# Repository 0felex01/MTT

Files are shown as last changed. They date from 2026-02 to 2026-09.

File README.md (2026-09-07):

# MTT (Movie-to-Text)
Offline SRT Reader for Arduino Uno R4 WiFi

Eventually capture footage of device in action and place here.

# Equipment
- [SD Card Reader](https://www.amazon.com/HiLetgo-Adater-Interface-Conversion-Arduino/dp/B07BJ2P6X6)
- [OLED Display](https://www.amazon.com/DWEII-Display-SSD1309-Interface-Electronic/dp/B0B2R3RBKL)
- [PowerBoost 1000C Battery Charger Circuit](https://www.adafruit.com/product/2465)
- [3.7V 1000mAh Battery](https://www.amazon.com/1000mAh-Lithium-Polymer-Rechargeable-Connector/dp/B0C2KNZBPD)

# Features
- File selection
- Timestamp selection
- Pausing and resuming
- Advancing and rewinding
- Full English and Japanese subtitles support

# Nice future ideas
- Change how to process the newlines in each segment to better align with the smaller display
- Get a bigger display, further research indicates this may not be practical.
- Add .sub support

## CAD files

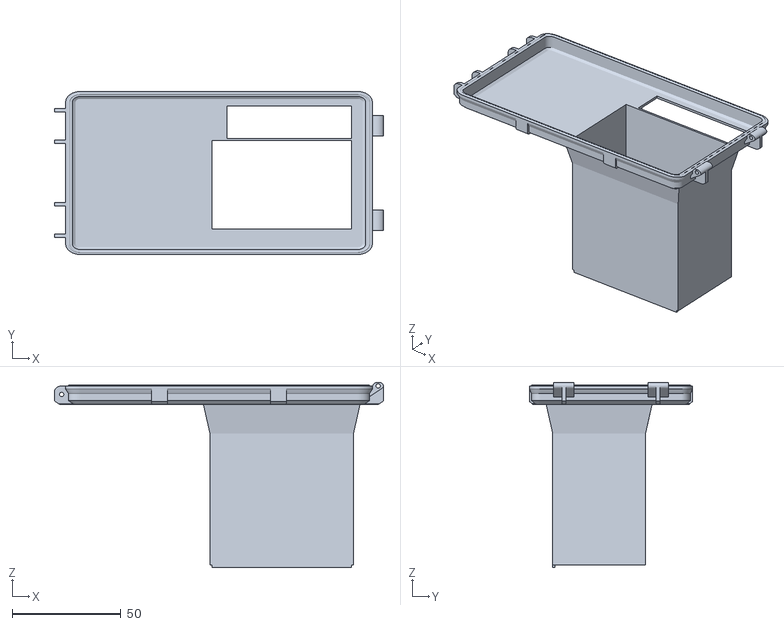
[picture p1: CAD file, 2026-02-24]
Blender/MTT top.stl
151.0 x 74.8 x 85.1

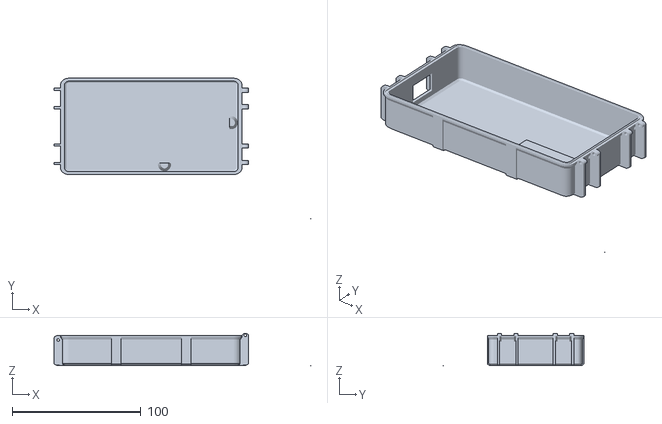
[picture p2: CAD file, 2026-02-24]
Blender/MTT bottom.stl
200.0 x 109.5 x 25.0

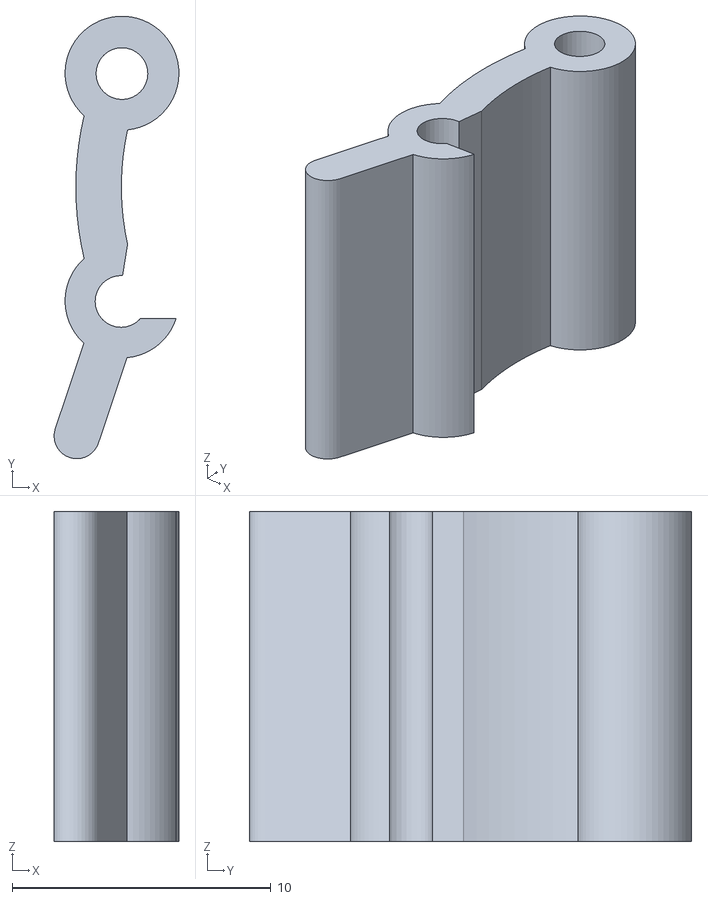
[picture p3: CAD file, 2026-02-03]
Blender/MTT Latches.stl
4.82 x 17.1 x 12.8

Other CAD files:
Blender/MTT Latches.blend
Blender/MTT bottom.blend
Blender/MTT top.blend

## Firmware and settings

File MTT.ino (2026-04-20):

#include <Arduino.h>

#define SD_CS 7
#define OLED_RST 8

#define SD_WAITING_MESSAGE "Waiting for SD"
#define TIME_GREETING_MESSAGE "Select your desired time"
#define RESET_MESSAGE "You may reset now"
#define CURSOR_SHAPE ">"
#define SRT_FILE_EXTENSION ".srt"
#define INITAL_TIMESTAMP "00:00:00:00"
#define MAX_ROWS 8

uint8_t DISPLAY_HEIGHT = 64;
uint8_t DISPLAY_WIDTH = 128;
uint8_t TILE_HEIGHT = 8;
uint8_t TILE_WIDTH = 8;
uint8_t FONT_HEIGHT = 5;
uint8_t DISPLAY_BOTTOM_ROW_TILE_X = 0;
uint8_t DISPLAY_BOTTOM_ROW_TILE_Y = (DISPLAY_HEIGHT / TILE_HEIGHT - 1);
uint8_t DISPLAY_BOTTOM_ROW_PIXEL_Y = (DISPLAY_BOTTOM_ROW_TILE_Y + 1) * TILE_HEIGHT;
uint8_t DISPLAY_TILE_WIDTH = DISPLAY_WIDTH / TILE_WIDTH;
uint8_t DISPLAY_BOTTOM_ROW_AREA_HEIGHT = TILE_HEIGHT / TILE_HEIGHT;

#include <U8g2lib.h>
#include <SPI.h>
#include <SdFat.h>
#include "OLED.h"
#include "PBs.h"
#include "SD_Reader.h"
#include "SRT.h"
#include "UI.h"

void setup() {
  Serial.begin(921600);
  while (!Serial);

	// UI
	String cursor = String(CURSOR_SHAPE);

  // Locale
  String locale = "EN";

  // Init PBs
  pinMode(PB_LEFT, INPUT_PULLUP);
  pinMode(PB_DOWN, INPUT_PULLUP);
  pinMode(PB_UP, INPUT_PULLUP);
  pinMode(PB_RIGHT, INPUT_PULLUP);
  pinMode(PB_B, INPUT_PULLUP);
  pinMode(PB_A, INPUT_PULLUP);

  // // Init OLED
  OLED_begin();

  // Init SD
  SdFat sd;
  OLED_print(SD_WAITING_MESSAGE, locale);
  /* while (!sd.begin(SD_CS, SPI_EIGHTH_SPEED)); */
  while (!sd.begin(SD_CS, SPI_HALF_SPEED));
  /* while (!sd.begin(SD_CS, SPI_DIV3_SPEED)); */

  // Read Files
  String files[MAX_FILES];
  unsigned int files_count = get_files(files);
  unsigned int cursor_pos = 0;
  files[0] = cursor + files[0]; // Cursor on first file
  draw_files(files, files_count, cursor_pos, "EN");
  draw_locale(locale, "EN");

  // File Select
  int input = 0;
  bool redraw = false;

  // Timestamps
  long periodic_times[PERIODIC_SIZE]; // Used to go to the closest subtitle after user provides time
  for (unsigned int i = 0; i < PERIODIC_SIZE; ++i) {
    periodic_times[i] = -1;
  }
  long periodic_pos[PERIODIC_SIZE]; // Used to go back and forth in subtitles
  for (unsigned int i = 0; i < PERIODIC_SIZE; ++i) {
    periodic_pos[i] = -1;
  }

  // Main Loop
  while (true) {
    input = check_buttons();
    switch (input) {
		case PB_DOWN: // Down one file
			if (cursor_pos < (files_count - 1)) {
				files[cursor_pos] = files[cursor_pos].substring(1);
				++cursor_pos;
				files[cursor_pos] = cursor + files[cursor_pos];
				redraw = true;
			}
			break;

		case PB_UP: // Up one file
			if (cursor_pos > 0) {
				files[cursor_pos] = files[cursor_pos].substring(1);
				--cursor_pos;
				files[cursor_pos] = cursor + files[cursor_pos];
				redraw = true;
			}
			break;

    case PB_B: // Switch locale
      if (locale == "EN") {
        locale = "JP";
      } else {
        locale = "EN";
      }
      redraw = true;
      break;

		case PB_A: // Select file
			String filename = files[cursor_pos].substring(1) + SRT_FILE_EXTENSION;

			SdFile subs;
			subs.open(filename.c_str(), O_READ);
			long amount_of_subs = gather_timestamps(subs, periodic_times, periodic_pos);

			// Prompt user to select time
			String current_timestamp = INITAL_TIMESTAMP;
			long chosen_time = 0;
			cursor_pos = 0;
			chosen_time = prompt_for_time(input, current_timestamp);

			// Skip to time
			bool skip_check = false;  // If the time is 0 or longer than the last subtitle, don't bother checking
			if (chosen_time == 0) {
				skip_check = true;
			}
			if (chosen_time > periodic_times[amount_of_subs - 1]) {
				subs.seekSet(periodic_pos[amount_of_subs - 1]);
				skip_check = true;
			}

			if (!skip_check) {
				for (long i = 0; i < amount_of_subs; ++i) {
					if (chosen_time < periodic_times[i]) {
						subs.seekSet(periodic_pos[i - 1]);
						break;
					}
				}
			}

			// Display subs
			subtitle first_subtitle;
			subtitle second_subtitle;

      // Populate first two subtitles then start rendering
      if (first_subtitle.index == 0) {
        read_subtitle(first_subtitle, subs);
      }
      if (second_subtitle.index == 0) {
        read_subtitle(second_subtitle, subs);
      }
      display_subs(subs, locale, periodic_times, periodic_pos, amount_of_subs, first_subtitle, second_subtitle);

			subs.close();
      Serial.println("End of subtitles");
			break;
    }

    if (redraw) {
      draw_files(files, files_count, cursor_pos, "EN");
      draw_locale(locale, "EN");
      redraw = false;
    }
  }
}

void loop() {
}

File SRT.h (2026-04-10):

#include <stdint.h>

#define LINE_FEED 10
#define CARRIAGE_RETURN 13
#define PERIODIC_SIZE 2000

#define LAST_SUBTITLE_RETURN -1
#define CLOSED_FILE_RETURN -2

#define GAP_MODE 1
#define SUBTITLES_MODE 2

#define SPEED_ADJUSTMENT_INCREMENTS 0.01
#define STARTING_FRAMES 100

struct subtitle {
  long index = 0;
  long from_time = 0;  // ms
  long to_time = 0;    // ms
  long duration = 0;   // ms
  String dialogue = "";
};

String read_next_line(SdFile& subs) {
  int data = 0;
  String buf;

  do {
    data = subs.read();
    buf += char(data);
  } while (data >= 0 && (data != LINE_FEED && data != CARRIAGE_RETURN));
  subs.read();  // Advance to next line

  return buf;
}

void go_to_prev_line(SdFile& subs) {
  int data = 0;
  unsigned int linefeed_count = 0;

  while (true) {
    if (subs.curPosition() <= 2) {
      return;
    }

    data = subs.read();
    if (data == LINE_FEED) {
      ++linefeed_count;
      if (linefeed_count == 6) {
        return;
      }
    }

    subs.seekSet(subs.curPosition() - 2);
  }
}

long calculate_from_time(const String& timestamps) {

  const char* ts = timestamps.c_str();

  int h = (ts[0] - '0') * 10 + (ts[1] - '0');
  int m = (ts[3] - '0') * 10 + (ts[4] - '0');
  int s = (ts[6] - '0') * 10 + (ts[7] - '0');
  int ms = (ts[9] - '0') * 100 + (ts[10] - '0') * 10 + (ts[11] - '0');

  return (long)h * 3600000L + (long)m * 60000L + (long)s * 1000L + ms;
}

long calculate_to_time(const String& timestamps) {

  const char* ts = timestamps.c_str() + 17;

  int h = (ts[0] - '0') * 10 + (ts[1] - '0');
  int m = (ts[3] - '0') * 10 + (ts[4] - '0');
  int s = (ts[6] - '0') * 10 + (ts[7] - '0');
  int ms = (ts[9] - '0') * 100 + (ts[10] - '0') * 10 + (ts[11] - '0');

  return (long)h * 3600000L + (long)m * 60000L + (long)s * 1000L + ms;
}

String clean_formatting(String message) {
  const char* tags[] = {
    "<b>", "</b>",
    "<i>", "</i>",
    "<u>", "</u>"
  };

  for (const char* tag : tags) {
    message.replace(tag, "");
  }

  message.replace("\r", "");
  return message;
}

String word_wrap(String message) {
  String result = "";

  unsigned int line_start = 0;
  unsigned int message_len = message.length();
  while (line_start < message_len) {
    // Find the end of the current line or existing newline
    int line_end = message.indexOf('\n', line_start);
    if (line_end == -1) line_end = message_len;

    String line = message.substring(line_start, line_end);
    unsigned int line_len = line.length();

    // Wrap the line if it's too long
    int start = 0;
    while ((unsigned int)start < line_len) {
      int end = start + MAX_CHAR_PER_LINE;
      if ((unsigned int)end >= line_len) {
        end = line_len;
      } else {
        // Find last space or punctuation before max width
        int wrap_pos = -1;
        for (int i = end; i > start; i--) {
          char c = line[i];
          if (c == ' ' || c == '?' || c == '.' || c == ',' || c == '!') {
            wrap_pos = i + 1;  // include punctuation/space
            break;
          }
        }
        if (wrap_pos != -1) end = wrap_pos;
      }

      result += line.substring(start, end);
      result += '\n';

      start = end;
      // Skip leading spaces
      while ((unsigned int)start < line_len && line[start] == ' ') start++;
    }

    line_start = line_end + 1;  // skip past existing newline
  }

  // Replace " -" with "\n-" as before
  result.replace(" -", "\n-");

  return result;
}

void read_subtitle(subtitle& given_subtitle, SdFile& subs) {
  // Subtitle index, skip
  long index = read_next_line(subs).toInt();
  given_subtitle.index = index;

  // Timestamps
  String timestamps = read_next_line(subs);
  long from_time = calculate_from_time(timestamps);
  long to_time = calculate_to_time(timestamps);
  /* long subtitles_duration = to_time - from_time; */
  given_subtitle.from_time = from_time;
  given_subtitle.to_time = to_time;
  long duration = to_time - from_time;
  given_subtitle.duration = duration;

  // Get all of the dialogue
  String dialogue = "";
  String current_read = "something";
  while (current_read.length() > 1) {
    current_read = read_next_line(subs);
    dialogue += current_read + "\n";
  }
  given_subtitle.dialogue = dialogue;

  return;
}

void transfer_subtitles(subtitle& first_subtitle, subtitle& second_subtitle) {
  subtitle temp = first_subtitle;
  first_subtitle = second_subtitle;
  second_subtitle = temp;
  second_subtitle.index = 0;
}

long gather_timestamps(SdFile& subs, long periodic_times[PERIODIC_SIZE], long periodic_pos[PERIODIC_SIZE]) {
  long periodic_idx = 0;
  long current_line = 0;
  long subs_counter = 0;

  while (subs.available()) {
    ++subs_counter;

    periodic_pos[periodic_idx] = subs.curPosition();
    read_next_line(subs);
    ++current_line;

    String timestamps = read_next_line(subs);
    ++current_line;

    long from_time = calculate_from_time(timestamps);
    periodic_times[periodic_idx] = from_time;
    ++periodic_idx;

    String current_message_line;
    do {
      current_message_line = read_next_line(subs);
      ++current_line;
    } while (current_message_line.length() > 1);
  }

  subs.seekSet(0);
  return subs_counter;
}

String make_paused_line(long timestamp) {
  long hours = timestamp / 3600000;
  timestamp %= 3600000;

  long minutes = timestamp / 60000;
  timestamp %= 60000;

  long seconds = timestamp / 1000;
  long millis = timestamp % 1000;

  char buffer[19];
  sprintf(buffer, "|| %02lu:%02lu:%02lu,%03lu", hours, minutes, seconds, millis);

  return String(buffer);
}
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

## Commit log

2024-11-03 *FIRST REAL TEST BUILD* added skipping to time and started putting some UI functions to UI.
    [MTT.ino, SRT.h]
2024-11-10 First real success test (still janky but didn't quit using device mid movie) Ignore hidden files Refactored main subtitles logic loop Added support for different modes with said logic loop (GAP and S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
    [MTT.ino, SRT.h]
2024-11-23 Resolved the compiler warnings and added some extra things.
    [SRT.h]
2025-03-15 sent out first pcb order
    [Peripherals Board-B_Cu.gbr, Peripherals Board-B_Mask.gbr, Peripherals Board-B_Paste.gbr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]
2025-05-03 added PBs to PCB and changed PB definitions to be reversed to accomodate PCB better
    [Peripherals Board-B_Cu.gbr, Peripherals Board-B_Mask.gbr, Peripherals Board-B_Paste.gbr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]
2025-05-03 made gerber zip
    [Peripherals Board-B_Cu.gbr, Peripherals Board-B_Mask.gbr, Peripherals Board-B_Paste.gbr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]
2025-05-18 pushbuttons were too far apart, made them 5.08mm instead of ~6mm
    [Peripherals Board-B_Cu.gbr, Peripherals Board-B_Mask.gbr, Peripherals Board-B_Paste.gbr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]
2025-09-07 fixes from test run today
    [MTT.ino]
2025-09-21 fixed rewind, added more timing logic, test run
    [SRT.h]
2026-02-03 Blender files added
    [MTT Latches.blend, MTT Latches.stl, MTT bottom.blend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]
2026-02-18 changed to i2c
2026-02-18 hw i2c at the point of heap corruption
2026-02-18 hw i2c fixed and 0.4 MTT PCB
    [Peripherals Board-B_Cu.gbr, Peripherals Board-B_Mask.gbr, Peripherals Board-B_Paste.gbr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]
2026-02-24 added 3d models
    [MTT Latches.blend, MTT bottom.blend, MTT bottom.gcode.3mf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]
2026-03-12 changed the sorting algo to use KickSort's Insertion sort
2026-03-15 Fix getFiles to include longer filenames and hide System Volume Information
    [SRT.h]
2026-03-18 basic working prototype of japanese support
2026-03-18 fixed up jp font usage to only apply to subtitles, also reworked PBs to not use delays
    [MTT.ino, OLED.h, SRT.h]
2026-03-19 last finishing touches to JP support, removed debug prints
2026-03-20 fixed first subtitle index bug and increased SPI speed, updated README
    [MTT.ino, SRT.h]
2026-03-31 added a speed scaler, up and down adjust by 1%, b displays current speed
2026-04-01 fixed prompt cursor from not moving to left and rewrote a few parts of it
    [MTT.ino, SRT.h]
2026-04-07 added partial rendering for scaler and paused text to avoid flashing whole screen when holding scale button
    [MTT.ino, SRT.h]
2026-04-10 more partial rendering fixes and code clean up
    [MTT.ino, OLED.h, SRT.h]
